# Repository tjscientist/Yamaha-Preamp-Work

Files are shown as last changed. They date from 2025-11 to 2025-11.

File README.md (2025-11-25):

# Yamaha Electric Grand (CP-70 and CP-80) Preamp Work

This all started out as a "simple" CP-80 restoration and (as usual) turned into a year long project... And still continues. Once I started really digging into things, I realized I needed to document my work both in words and video. Initially this documentation was simply so I remembered what I was doing but eventually, I realized there were others out there struggling with the same issues I had been running into. These issues are primarily spare parts, readable schematics, and in depth repair knowledge. To that end, I decided to put my work up here on github so that others could not only benefit from what I have done, but also point out any mistakes I may be making as well as contribute their own knowledge.

What you see up here currently (as of November 2025) are a collection of files, specs, and simulations I have put together and am trying to get organized into something cohesive. Below I will delineate each section and what is in it. As always, please feel free to comment, ask questions, and/or add your own experiences.

This is still an ongoing endeavor and there is much I want to do. I am always open to suggestions.

## Why Even Bother?

I know a lot of people will look at this and just ask, "Why not just do the direct out modification and call it all good?"

The simple answer is I did do that and it sounds pretty good. Then I ran it through my Art Pro Tube preamp... Nice. Then through my restored BOSS CE-1.. Better. Then I wanted the nice stereo tremolo you get from the original preamp and had to work on that. Finally, I just thought why not get back to basics. Do what I do best which is restore everything to as original as possible. So that is what I am doing. I love buying, restoring, and using vintage equipment and I have a lot of it. Several Fender Rhodes pianos, Clavinets, Wurlitzers, B3, A100... And the list goes on. And I know there are many others out there just as crazy as I am when it comes to this, so here we are.

## Altium Files

I use Altium in me every day life as my primary tool for designing electronic schematics and PCBs but I do understand that not everyone has access to this tool. If you do have access to Altium, you will find the entire schematic and part libraries in the **Altium Files** folder. On the other hand, if you do not have access to Altium, do not despair as you will find what is known as a Smart PDF of the schematic in the **Documents** folder named "Schematic - CP80 Preamp - SmartPDF."

## SmartPDF Schematic

The smartPDF schematic, named "Schematic - CP80 Preamp - SmartPDF", is a very useful document. In it you will find the preamp schematic which I have redrawn and find much more readable. But wait, there's more! By clicking on any part in the schematic, you will get a pop-up which includes the original part number, manufacturer, part description, and a comment field where I have listed what I suggest to use if you want or need to replace that particular part. Some parts have a lot of information while others do not require so much. Below is an example showing what appears when FET1 is clicked:

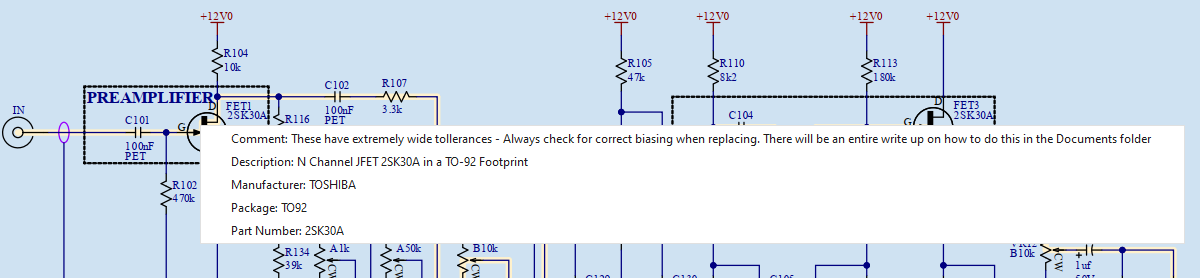
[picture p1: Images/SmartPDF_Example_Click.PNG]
SmartPDF_Example_Click


Additionally on the schematic, you will see my notes and highlights. The following is from the bottom of the PDF and explains a bit of the information it contains:

*The MCD-527 LDRs (Light Dependent Resistors):*
*TRD101 and TRD102, are split into 2 parts each. These parts are the LED light source (Part B - Highlighted Green) and the Photoresistor (Part A - Highlighted Red).* 

*Signal Flow:*
*Audio enters from the piezo pickups at the upper left and is highlighted in yellow all the way to the buffer amplifiers where it is split into unvbalanced  high and balanced low impeadance stereo signals. The left high impeadance signal is highlighted in red while the right high impeadance signal is highlighted in green. The left low impeadance signal is highlighted in purple while the right low impeadance signal is highlighted in pink.*

*The tone brilliance signals are detailed on the far right, external controls are labeled in bold red, and adjustment pots are highlighted in bright green boxes.*

*Clicking on any component in the PDF file will show the original part number, part specifications, and notes on replacement parts.*

*Using the PDF file bookmarks, you can jump to any specific part or net.*

## Part Data Sheets

This is pretty self explanatory. In the Part Data Sheets folder you will find data sheets for some of the parts in the preamp. Most of these are simply data sheets that are hard to find, so I included them here as an easy reference. Additionally, when I am researching acceptable alternatives, I put those data sheets in there as well. I may add more over time.

## TINA-TI Spice Files

For those that are not familiar with TINA-TI, it is a free, SPICE-based circuit simulation software from Texas Instruments (TI) and DesignSoft that is used to design, test, and analyze analog, digital, and mixed electronic circuits. It includes a graphical interface for schematic capture, analysis capabilities like DC, transient, and frequency domain, and virtual instruments. The program is a simplified version of the full TINA Design Suite but remains powerful enough for complex circuits.  For more information check out TINA-TI's website: [https://www.ti.com/tool/TINA-TI](https://www.ti.com/tool/TINA-TI).

The main files TINA uses have a TSC extension and the graphing files have a tdr extension. Below you can see the schematic which I have entered into TINA (CP-80.TSC):

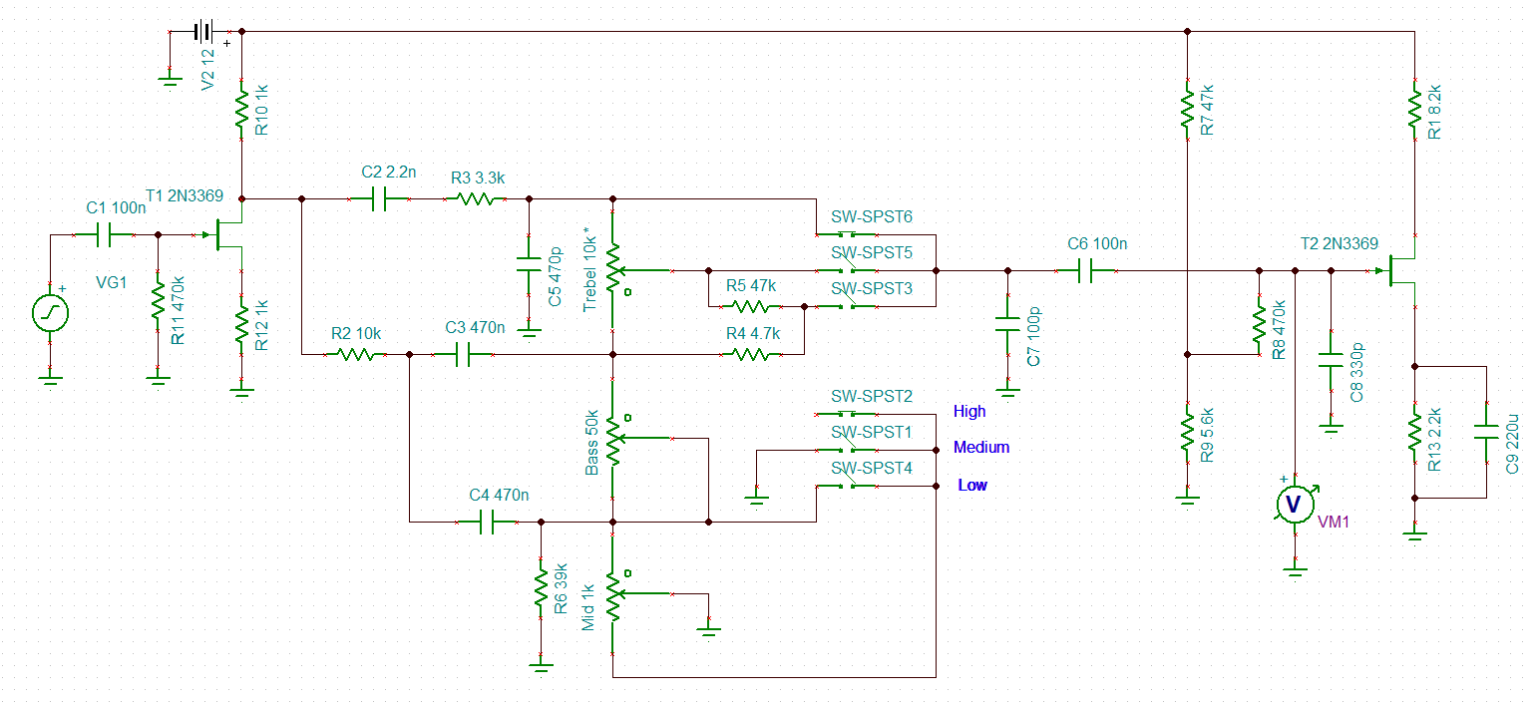
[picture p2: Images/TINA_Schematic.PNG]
TINA_Schematic


There is a document in the Documents folder (and eventually a video link) "CP-80 Preamp TINA-TI Simulations" that explains the circuit and how to generate simulations like the one below (this one shows the frequency response from 1hZ to 20kHz with the Brilliance Switch set to High, Bass and Treble controls at 99%, and the Mid control set to 10 different settings as shown in the legend of the plot):

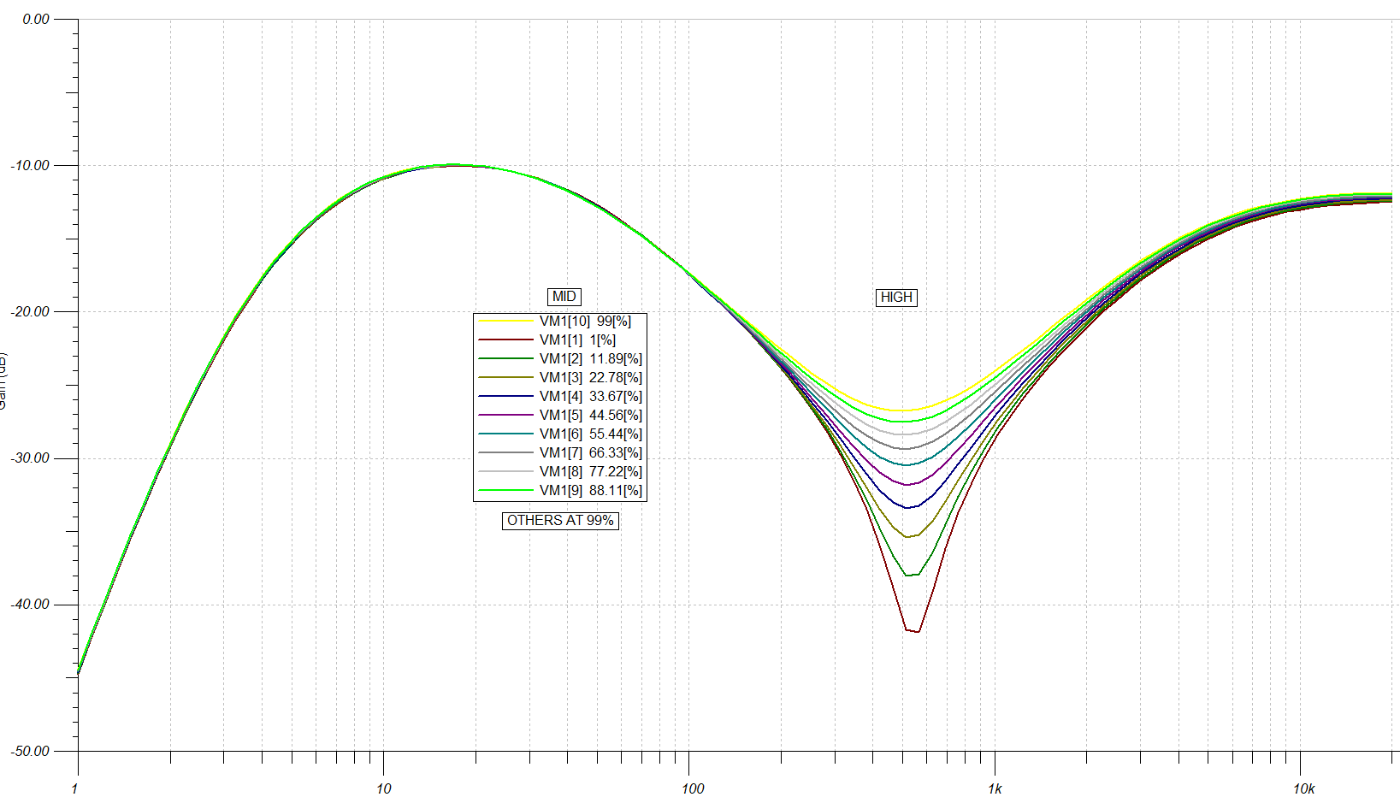
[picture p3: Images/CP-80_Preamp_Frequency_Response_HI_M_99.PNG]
CP-80_Preamp_Frequency_Response_HI_M_99


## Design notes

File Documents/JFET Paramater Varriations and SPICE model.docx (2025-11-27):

JFET SPICE MODEL:

The SPICE model for our N Channel JFET, the 2SK30 is shown below (the note on the last entry refers to a CQ magazine article from July, 1988 as the model source):

*2SK30
*id(R 0.3-0.75 / O 0.6-1.4 / Y 1.2-3.00 / GR 2.6-6.5)
.model J2SK30r NJF(vto=-0.8v beta=0.75m lambda=0 cgd=2.6p cgs=8.2p
+ dev 10% LOT 60%)
.model J2SK30o NJF(vto=-1.1v beta=0.75m lambda=0 cgd=2.6p cgs=8.2p
+ dev 10% LOT 60%)
.model J2SK30y NJF(vto=-1.8v beta=0.75m lambda=0 cgd=2.6p cgs=8.2p
+ dev 10% LOT 60%)
.model J2SK30gr NJF(vto=-2.8v beta=0.75m lambda=0 cgd=2.6p cgs=8.2p
+ dev 10% LOT 60%)

.model J2SK30atm NJF(beta=.768m vto=-2.70 cgd=2.6p cgs=8.2p dev 10% LOT 60%)
* CQ 1988/7

DEV and LOT in the JFET SPICE Model:
DEV 10% LOT 60% is used in SPICE simulations to define statistical variations for device parameters, enabling worst-case and Monte Carlo analyses.

Explanation of the Parameters:
These parameters define how much a specific model parameter (like a transistor's current gain or a resistor's value) can vary from its nominal value during a statistical simulation. This is crucial for checking circuit robustness and manufacturing yield.

- DEV (Deviation): This specifies the intra-die variation, which is the random mismatch between components on the same integrated circuit (die). The value 10% means the parameter can randomly vary by up to ±10% from its nominal value due to local process variations.
- LOT: This specifies the inter-die (or lot-to-lot) variation. This accounts for the systematic shift in parameters that affects all devices on an entire wafer or in a specific manufacturing batch (lot). The value 60% means the parameter's nominal value can vary by up to ±60% from the global average value across different manufacturing lots.

IDSS Classification note in the data sheet:
In a JFET datasheet, the IDSS classification note refers to the practice of the manufacturer sorting JFETs into different performance grades (listed as R, O, Y, and GR in the 2SK30 datasheet) based on their specific, measured Zero-Gate-Voltage Drain Current.

Understanding the Classification:

- IDSS Definition: I_(DSS) is the maximum current that can flow from the drain to the source when the gate-source voltage ( V_(GS) ) is 0V (gate and source shorted together) and the JFET is in the saturation region.
- Manufacturing Variability: The exact value of I_(DSS) and the associated pinch-off voltage ( V_P ) can vary significantly even among JFETs of the same part number due to slight inconsistencies in the manufacturing process. This variability is inherent to JFETs and is comparable to the beta factor ( h_(FE) ) in BJTs.
- Binning/Grading: To provide designers with more predictable components for specific applications, manufacturers test the produced JFETs and group (or "bin") them into different classifications, each with a tighter range of I_(DSS) values than the overall part number might suggest.

Practical Implications for Design:
The classification allows designers to select the appropriate JFET grade for their circuit, particularly when the design depends on a specific current range or requires matched pairs for differential amplifiers.

SPICE Syntax for a JFET:
The SPICE syntax for an N-channel JFET model is .MODEL ModelName NJF(parameters), where ModelName is a user-defined name for the model and parameters are a list of values that define the JFET's characteristics, such as beta, Vto, rd, and rs. An example of a JFET element in the netlist is Jname <drain> <gate> <source> ModelName.

Model definition:

- MODEL: A directive used to define a model.
- ModelName: A unique name you assign to this specific JFET model.
- NJF: Specifies that this is an N-channel Junction Field-Effect Transistor model.
- (parameters): A list of key-value pairs that define the JFET's electrical properties.
  - beta: The transconductance parameter.
  - Vto: The pinch-off voltage.
  - rd: The drain resistance.
  - rs: The source resistance.
  - is: Saturation current.
  - lambda: Channel-length modulation parameter.
  - cgs: Gate-source capacitance.
  - cgd: Gate-drain capacitance.
  - fc: Forward-bias cap voltage dependence coefficient.
  - m: Cap coefficient variation with gate voltage.
  - n: Coefficient for gate voltage dependence of capacitance.
  - xti: Temperature dependence of saturation current.

Element instance:

- Jname: A unique name for the JFET device instance in the circuit.
- <drain>: The node connected to the drain terminal.
- <gate>: The node connected to the gate terminal.
- <source>: The node connected to the source terminal.
- ModelName: The name of the model you are referencing

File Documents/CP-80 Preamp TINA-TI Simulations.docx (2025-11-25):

This document is intended to be used with the TINA-TI program (www.ti.com/tool/TINA-TI) loaded with the CP-80.TSC spice file from the TINA Spice Files Folder and the 2SK30 N-channel JFET data sheet (located in the “Part Data Sheets” folder).

The main reasons I decided to go through the work of entering the entire schematic into TINA are as follows:

- JFETs have extremely wide parameters (e.g. VGS can range from -0.4 to -5V and IDSS can range from 0.3 to 6.5mA) so I wanted to characterize the circuit over this range.
- Certain parts are very difficult to find if they need replacement, such as the 2 audio transformers for the balanced line out. I want to know that my replacements will not alter the original sound.

The schematic drawn in the CP-80 Spice file is a slightly modified version of the actual CP-80 preamp schematic. As you can see, the 3 position Brilliance switch is set up to manually open and close each contact. Additionally, you can see there are 4 options for the 2SK30 JFET. These options cover the 4 IDSS classifications from the data sheet.

Before we continue, we need to talk about JFETs, their extremely wide parameter set (i.e. Very large part to part variations), and a couple of definitions.

IDSS (zero-gate-voltage drain current) is a characteristic that varies between individual devices, even those of the same part number. However, a JFET's characteristics are determined by its IDSS value, and this value, along with the pinch-off voltage ( V_(GS(off)) ), can be used to classify or group devices for specific applications like voltage-controlled resistors or current sources. Devices are primarily classified by their type, either N-channel or P-channel, which dictates the polarity of the gate-source voltage required to control the drain current.

How JFETs are classified and characterized

- Channel Type: The most fundamental classification is the channel type, which can be either N-channel or P-channel. In our case the only JFETs we use are the 2SK30 N-channel JFET.
  - N-channel: Requires a negative gate-source voltage to decrease drain current.
  - P-channel: Requires a positive gate-source voltage to decrease drain current.
- IDSS and V_(GS(off)) : Within a channel type, devices can be grouped based on IDSS and V_(GS(off)) values, which are measured through testing. When manufacturers do this, it is called binning.
  - IDSS (Zero-gate-voltage drain current): The drain-source current when the gate-source voltage ( V_(GS) ) is zero. This is a measure of the maximum current a JFET can conduct at V_(GS) =0 .
  - V_(GS(off)) (Pinch-off voltage): The gate-source voltage required to turn the JFET off (reduce the drain current to near zero).
  - These two parameters are directly related, and a higher IDSS will have a different corresponding V_(GS(off)) value than a lower IDSS.

Applications where IDSS and VGS(off) are used for grouping or binning

- Matching: Devices can be grouped or "matched" by similar IDSS and V_(GS(off)) values for applications where this is critical, such as stereo audio amplifiers or balanced circuits.
- Current Source: A JFET with a specific IDSS can be used to create a current source or sink. By adding a resistor from the source to ground, the current can be set to a specific value, and the IDSS value of the device can be used to calculate the appropriate resistor value.
- Voltage Controlled Resistor: In a voltage-controlled resistor application, the IDSS value is used in conjunction with V_(GS(off)) to select devices that have the same "on-resistance" ( R_(DS(on)) ) range.

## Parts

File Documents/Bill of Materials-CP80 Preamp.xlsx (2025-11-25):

Name | Description | Designator | Quantity | Manufacturer 1 | Manufacturer Part Number 1 | Supplier 1 | Supplier Part Number 1
1N4148 | General purpose Rectifier Diode, 300mA, 35V V(RRM) If replacing and you cannot find the original, a 1N4148 should be fine | D202 | 1 | onsemi | 1N4148 | DigiKey | 1N4148FS-ND
1N5231BTR | Zener Diode 5.1 V 500 mW 5% If replacing, any 5V1 zener capable of 500mW is fine | D101, D102 | 2 | Microchip | 1N5231B/TR | Mouser | 494-1N5231B/TR
1N5246B | Zener Diode 16V2 500 mW 5% If replacing, any 16V2 zener with 500mW capability will work. | D201 | 1 | onsemi | 1N5246BTR | DigiKey | 1N5246BTRFSCT-ND
105BPS100M | 1uf, 50V, 20%, Electrolytic If these need replacement, just use a low ESR 1uF, 50V, 10% or 20% Electrolytic that is the correct physical size | C107, C109, C114, C121, C122 | 5 | Cornell Dubilier | 105BPS100M | DigiKey | 105BPS100M-ND
112AX | Phone Jack, 6.35mm (0.250", 1/4", Mono Connector, 1 Switch Contact If replacing, replace with same high quality | J1, J2, J3, J4 | 4 | Switchcraft | 112AX | DigiKey | SC1316-ND
225BPS050M | 2.2uF ±20% 16V BiPolar Electrolytic If these are replaced, be sure to use BiPolar Electrolytics. I would go with ±10% tollerance and a minimum 25V. Just make sure they physically are the correct size. | C124, C127 | 2 | Cornell Dubilier | 225BPS050M | DigiKey | 225BPS050M-ND
3266W-1-103LF | 10k Linear taper 20% .250W carbon Adjustable Resistor - Trimmer If replacing, use a 1/4W cermet multi turn with 10% tolerance as they are much better. Find a physical size that works... I will do more research on these as I would also (personally) use a multiturn pot if I can find one that fits. | VR12 | 1 | Bourns | 3266W-1-103LF | DigiKey | 3266W-103LF-ND
3266W-1-104LF | 100k Linear taper 20% .250W carbon Adjustable Resistor - Trimmer If replacing, use a 1/4W cermet multi turn with 10% tolerance as they are much better. Find a physical size that works... I will do more research on these as I would also (personally) use a multiturn pot if I can find one that fits. | VR8, VR9, VR10, VR11 | 4 | Bourns | 3266W-1-104LF | DigiKey | 3266W-104LF-ND
3266W-1-253LF | Original was 22k Linear 20% .250W carbon Adjustable Resistor - Trimmer If replacing, use a 1/4W cermet multi turn with 10% tolerance as they are much better. I am using a 25k as they are much easier to source and it will work just fine. Find a physical size that works... I will do more research on these as I would also (personally) use a multiturn pot if I can find one that fits. | VR7 | 1 | Bourns | 3266W-1-253LF | DigiKey | 3266W-253LF-ND
B32671L1222J000 | 2200pF ±20% 20V (or higher) PET Capacitor These were originally Mylar Film (PET) but I suggest replacing with metallized polypropylene (MKP / PP). Just ensure a propper lead spacing and fit. | BH-C102, BL-C102, BM-C102, C102, C106 | 5 | EPCOS | B32671L1222J000 | DigiKey | 495-3206-ND
BC549BTA | Small Signal Bipolar Transistor, 0.6A I(C), 40V V(BR)CEO, 1-Element, NPN, Silicon, TO-236 If replacing, a BC549BTA or equivelant will work fine. These are just for turnming on the LEDs in the LDRs. | TR101, TR102, TR201 | 3 | onsemi | BC549BTA | DigiKey | BC549BTACT-ND
ECW-FE2W104JA | 100nF (0.1uf) ±20% 20V (or higher) PET Capacitor These were originally Mylar Film (PET) but I suggest replacing with metallized polypropylene (MKP / PP). Just ensure a propper lead spacing and fit. | BH-C103, BL-C103, BM-C103, C101, C103, C112, C113, C115, C117, C119, C120, C126 | 12 | Panasonic | ECWFE2W104JA | DigiKey | 10-ECW-FE2W104JA-ND
GD90025 | The original was a GD90025 - I think these can be replaced with Hammond audio signal transformers... I need to put these on the analyzer to see. | LT1, LT2 | 2
L7812ABV | Originally a FS7812L Linear Voltage Regulator IC Positive Fixed 1 Output 1.5A TO-220 If replacing, there are many pin for pin compatible devices | IC201 | 1 | STMicroelectronics | L7812ABV | DigiKey | 497-1449-5-ND
Lever Switch | Lever Switch, 2P3T - Unknown replacement as of yet. | S1 | 1
MFR-25FTE52-1K | 1k 10% 1/4 Watt Resistor All resistors are 10% 1/4 Watt. I suggest any replacement use 1% 1/4 Watt metal film. | R103, R122 | 2 | Yageo Group | MFR-25FTE52-1K | DigiKey | 13-MFR-25FTE52-1KCT-ND
MFR-25FTE52-1K2 | 1k2 10% 1/4 Watt Resistor All resistors are 10% 1/4 Watt. I suggest any replacement use 1% 1/4 Watt metal film. | R202 | 1 | Yageo Group | MFR-25FTE52-1K2 | DigiKey | 13-MFR-25FTE52-1K2CT-ND
MFR-25FTE52-2K2 | 2k2 10% 1/4 Watt Resistor All resistors are 10% 1/4 Watt. I suggest any replacement use 1% 1/4 Watt metal film. | R109, R120, R151, R153, R204, R205 | 6 | Yageo Group | MFR-25FTE52-2K2 | DigiKey | 13-MFR-25FTE52-2K2CT-ND
MFR-25FTE52-3K3 | 3k3 10% 1/4 Watt Resistor All resistors are 10% 1/4 Watt. I suggest any replacement use 1% 1/4 Watt metal film. | BH-R107, BL-R107, BM-R107, R107 | 4 | Yageo Group | MFR-25FTE52-3K3 | DigiKey | 13-MFR-25FTE52-3K3CT-ND
MFR-25FTE52-4K7 | 4k7 10% 1/4 Watt Resistor All resistors are 10% 1/4 Watt. I suggest any replacement use 1% 1/4 Watt metal film. | BH-RS2, BL-RS2, BM-RS2, RS2 | 4 | Yageo Group | MFR-25FTE52-4K7 | DigiKey | 13-MFR-25FTE52-4K7CT-ND
MFR-25FTE52-5K6 | 5k6 10% 1/4 Watt Resistor All resistors are 10% 1/4 Watt. I suggest any replacement use 1% 1/4 Watt metal film. | R108, R126, R158, R161, R206 | 5 | Yageo Group | MFR-25FTE52-5K6 | DigiKey | 13-MFR-25FTE52-5K6CT-ND
MFR-25FTE52-8K2 | 8k2 10% 1/4 Watt Resistor All resistors are 10% 1/4 Watt. I suggest any replacement use 1% 1/4 Watt metal film. | R110 | 1 | Yageo Group | MFR-25FTE52-8K2 | DigiKey | 13-MFR-25FTE52-8K2CT-ND
MFR-25FTE52-10K | 10k 10% 1/4 Watt Resistor All resistors are 10% 1/4 Watt. I suggest any replacement use 1% 1/4 Watt metal film. | BH-R116, BL-R116, BM-R116, R104, R116, R152, R162 | 7 | Yageo Group | MFR-25FTE52-10K | DigiKey | 13-MFR-25FTE52-10KCT-ND
MFR-25FTE52-22K | 22k 10% 1/4 Watt Resistor All resistors are 10% 1/4 Watt. I suggest any replacement use 1% 1/4 Watt metal film. | R135, R136 | 2 | Yageo Group | MFR-25FTE52-22K | DigiKey | 13-MFR-25FTE52-22KCT-ND
MFR-25FTE52-27K | 27k 10% 1/4 Watt Resistor All resistors are 10% 1/4 Watt. I suggest any replacement use 1% 1/4 Watt metal film. | R115, R129, R132, R139, R143, R147 | 6 | Yageo Group | MFR-25FTE52-27K | DigiKey | 13-MFR-25FTE52-27KCT-ND
MFR-25FTE52-39K | 39k 10% 1/4 Watt Resistor All resistors are 10% 1/4 Watt. I suggest any replacement use 1% 1/4 Watt metal film. | BH-R134, BL-R143, BM-R143, R111, R112, R134, R156, R157, R159, R160 | 10 | Yageo Group | MFR-25FTE52-39K | DigiKey | 13-MFR-25FTE52-39KCT-ND
MFR-25FTE52-47K | 47k 10% 1/4 Watt ResistorAll resistors are 10% 1/4 Watt. I suggest any replacement use 1% 1/4 Watt metal film. | BH-RS1, BL-RS1, BM-RS1, R105, R125, RS1 | 6 | Yageo Group | MFR-25FTE52-47K | DigiKey | 13-MFR-25FTE52-47KCT-ND
MFR-25FTE52-100K | 100k 10% 1/4 Watt Resistor All resistors are 10% 1/4 Watt. I suggest any replacement use 1% 1/4 Watt metal film. | R117, R119, R130, R133, R140, R144, R148, R154, R155 | 9 | Yageo Group | MFR-25FTE52-100K | DigiKey | 13-MFR-25FTE52-100KCT-ND
MFR-25FTE52-100R | 100 10% 1/4 Watt Resistor All resistors are 10% 1/4 Watt. I suggest any replacement use 1% 1/4 Watt metal film. | R201, R203 | 2 | Yageo Group | MFR-25FTE52-100R | DigiKey | 13-MFR-25FTE52-100RCT-ND
MFR-25FTE52-180K | 180k 10% 1/4 Watt Resistor All resistors are 10% 1/4 Watt. I suggest any replacement use 1% 1/4 Watt metal film. | R113, R127, R128, R137, R141, R145 | 6 | Yageo Group | MFR-25FTE52-180K | DigiKey | 13-MFR-25FTE52-180KCT-ND
MFR-25FTE52-220K | 220k 10% 1/4 Watt Resistor All resistors are 10% 1/4 Watt. I suggest any replacement use 1% 1/4 Watt metal film. | R114, R123, R131, R138, R142, R146 | 6 | Yageo Group | MFR-25FTE52-220K | DigiKey | 13-MFR-25FTE52-220KCT-ND
MFR-25FTE52-330R | 330 10% 1/4 Watt Resistor All resistors are 10% 1/4 Watt. I suggest any replacement use 1% 1/4 Watt metal film. | R118, R124, R149, R150 | 4 | Yageo Group | MFR-25FTE52-330R | DigiKey | 13-MFR-25FTE52-330RCT-ND
MFR-25FTE52-470K | 470k 10% 1/4 Watt Resistor All resistors are 10% 1/4 Watt. I suggest any replacement use 1% 1/4 Watt metal film. | R102, R106, R121 | 3 | Yageo Group | MFR-25FTE52-470K | DigiKey | 13-MFR-25FTE52-470KCT-ND
NSL-32SR2S | This original part was a MCD-527 LDR (Light Dependent Resistor). If replacing, the Advanced Photonix NSL-32SR2S OPTOISO PHOTOCELL OPTOCOUPLER is a very close alternative and is available on DigiKey. I will do more research on this (put one in a PreAmp) to see if any other tweaks are necessary. | TRD101, TRD102 | 2 | Advanced Photonix | NSL-32SR2S | DigiKey | NSL-32SR2S-ND
P092N-QC20BR20K | 20k Ohm 2 Gang Linear Through Hole Potentiometer 1.0 Turns Carbon 0.125W, 1/8W PC Pins Replace with Conductive Plastric or Cermet. Ensure proper mechanical fit. | VR1, VR5 | 2 | BI Technologies | P092N-QC20BR20K | Master Electronics | P092N-QC20BR20K
P160KN-0QD15B10K | 10k Ohm 1 Gang Linear Through Hole Potentiometer 1.0 Turns Carbon 0.125W, 1/8W PC Pins Replace with conductive plastic | VR4 | 1 | BI Technologies | P160KN-0QD15B10K | DigiKey | 987-1308-ND
P160KNP-0FC25A50K | 50k Ohm 1 Gang Logarithmic Through Hole Potentiometer 1.0 Turns Carbon 0.125W, 1/8W PC Pins Replace with conductive plastic. | BH-VR2, BL-VR2, BM-VR2, VR2 | 4 | BI Technologies | P160KNP-0FC25A50K | Mouser | 858-P160KNP0FC25A50K
P160KNP-0QC15A1K | 1k Ohm 1 Gang Logarithmic Through Hole Potentiometer 1.0 Turns Carbon 0.125W, 1/8W PC Pins Replace with conductive plastic. | BH-VR3, BH-VR4, BL-VR3, BL-VR4, BM-VR3, BM-VR4, VR3 | 7 | BI Technologies | P160KNP-0QC15A1K | Mouser | 858-P160KNP0QC15A1K
PDB182-K220K-104B | 100k Ohm 2 Gang Linear Through Hole Potentiometer 1.0 Turns Carbon 0.125W, 1/8W PC Pins Replace with conductive plastic or cermet if possible. This one is carbon. | VR6 | 1 | Bourns | PDB182-K220K-104B | DigiKey | PDB182-K220K-104B-ND
PFR5331J630J11L4BULK | 330pF ±20% 20V (or higher) PET Capacitor These were originally Mylar Film (PET) but I suggest replacing with metallized polypropylene (MKP / PP). Just ensure a propper lead spacing and fit. | C130, C131 | 2 | KEMET | PFR5331J630J11L4BULK | DigiKey | 399-7718-ND
POWER SW | Slide switch. Need to find replacement part number | PS1 | 1
R76MF24705050J | 47nF (0.047uf) ±20% 20V (or higher) PET Capacitor These were originally Mylar Film (PET) but I suggest replacing with metallized polypropylene (MKP / PP). Just ensure a propper lead spacing and fit. | C104 | 1 | KEMET | R76MF24705050J | DigiKey | 399-R76MF24705050J-ND
R76QF0470DQ00J | 470pF ±20% 20V (or higher) PET Capacitor These were originally Mylar Film (PET) but I suggest replacing with metallized polypropylene (MKP / PP). Just ensure a propper lead spacing and fit. | BH-C128, BL-C128, BM-C128, C108, C128, C202 | 6 | KEMET | R76QF0470DQ00J | DigiKey | 399-R76QF0470DQ00JCT-ND
R76UI0100SE40J | 100pF ±20% 20V (or higher) PET Capacitor These were originally Mylar Film (PET) but I suggest replacing with metallized polypropylene (MKP / PP). Just ensure a propper lead spacing and fit. | BH-C129, BL-C109, BM-C129, C129 | 4 | KEMET | R76UI0100SE40J | DigiKey | 399-R76UI0100SE40J-ND
RC4558IP | Dual General-Purpose Operational Amplifier, 10 to 30 V, 0 to 70 degC, 8-pin SOP (PW8), Green (RoHS & no Sb/Br) If replacing, replace with the same as removed. These are still available. | U102 | 1 | Texas Instruments | RC4558IP | DigiKey | 296-17460-5-ND
Switch, Toggle, DPST | This is a specialized switch with no known replacement. Will research more. | S2 | 1
T356A474K035AT | .47µF TANT 20% 16V The originals were most likely 20% @ 16V with an ESR of 50 Ohms @ 100Khz. If replaced I would use 10%, 20V with 5 Ohm ESR @ 100Khz | BH-C110, BH-C111, BL-C110, BL-C111, BM-C110, BM-C111, C110, C111 | 8 | KEMET | T356A474K035AT | DigiKey | 399-3617-ND
Transistor, JFET, N Ch, TO-92 | Original was an N Channel JFET 2SK30A in a TO-92 Footprint These have extremely wide tollerances - Always check for correct biasing when replacing. There will be an entire write up on how to do this in the Documents folder | FET1, FET2, FET3, FET4, FET5, FET6, FET7, FET8, FET9 | 9 | Toshiba | 2SK30A-Y | Win Source | 18270-2SK30A-Y
UES1H100MPM | 10µF 20% 25V electrolytic Capacitor If replacing, use a 10uF 10% 50V electrolytic woth a low ESR. Going to 50V will allow for 10% and a lower ESR as long as it still physically fits well. | C116, C118, C123, C125 | 4 | Nichicon | UES1H100MPM | DigiKey | 493-15033-ND
UKT1V221MPD | 220µF 20% 25V Electrolytic Capacitor If replacing, use a good quality 220uF 20% (or better) 25V Electrolytic Capacitor that physically fits correctly | C105, C201, C203, C204 | 4 | Nichicon | UKT1V221MPD | DigiKey | 493-15452-ND
WP7113ID | Single Color (Red) LED If replacing, any standard LED with a forward voltage of 1V7 to 2V2 will work fine | D1 | 1 | Kingbright | WP7113ID | DigiKey | 754-1264-ND
XLR-2A-32 | 2 Position Circular Connector Plug, Female Sockets Solder XLR-2A-32 is the male version on the piano while XLR2A11C Is the female connector on the cable | J201 | 1 | ITT / Cannon | XLR2A32 | Master Electronics | XLR2A32
XLR-3-32 | 3 Position Circular Connector Receptacle, Male Pins Solder Cup Replace with same if replacing | J5, J6 | 2 | ITT / Cannon | XLR332 | DigiKey | 1003-1238-ND

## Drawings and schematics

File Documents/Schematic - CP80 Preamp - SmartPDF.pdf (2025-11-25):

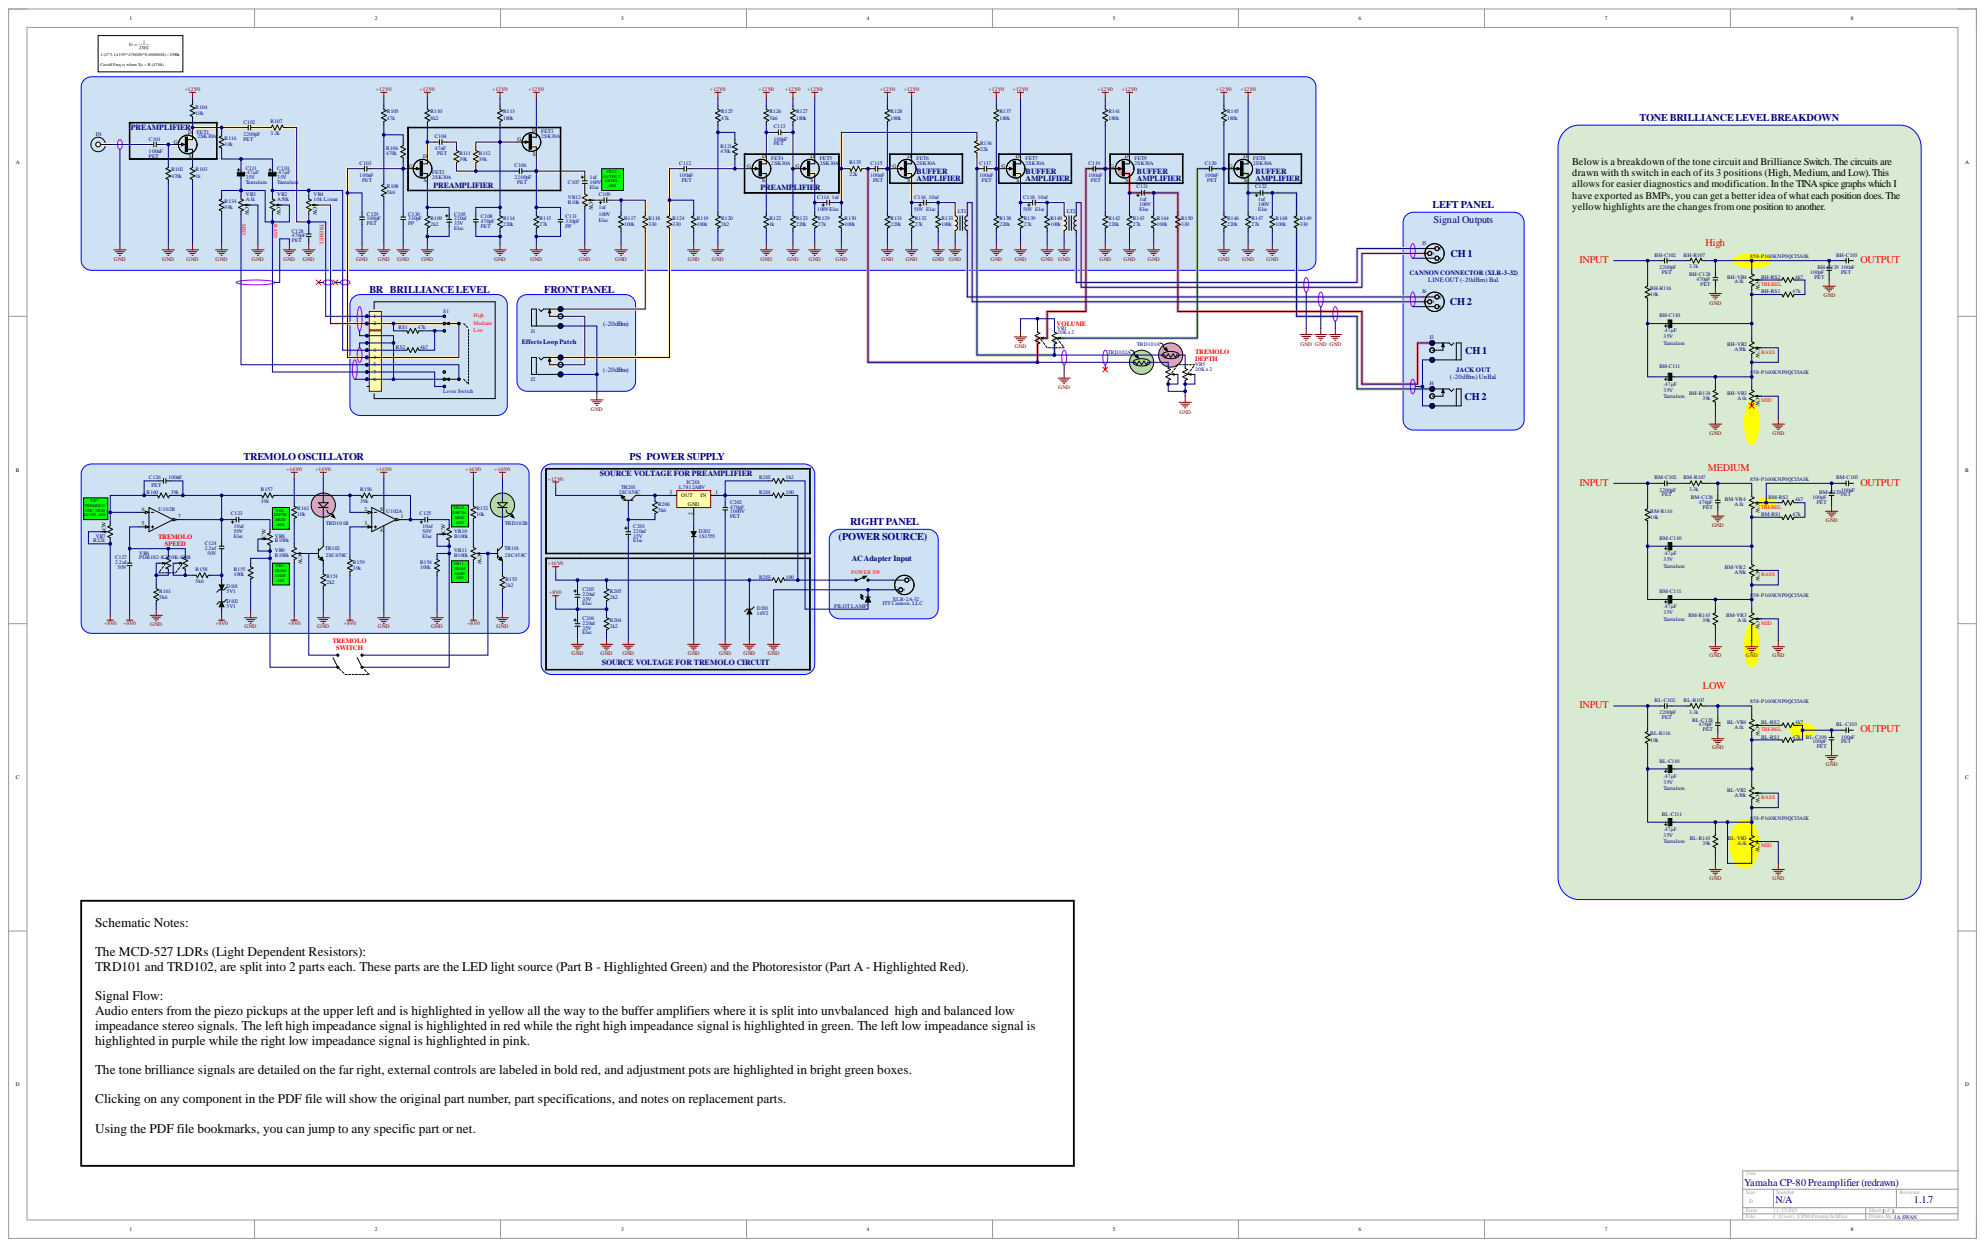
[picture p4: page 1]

Cutoff Freq is where Xc = R (470k)

Below is a breakdown of the tone circuit and Brilliance Switch. The circuits are
drawn with th switch in each of its 3 positions (High, Medium, and Low). This

allows for easier diagnostics and modification.In the TINAspice graphs which I
have exported as BMPs, you can get a better idea of what each position does. The
yellow highlights are the changes from one position to another.

C203 R205 220uf 35V Elec 2k2

PILOT LAMP

XLR-2A-32 ITT Cannon, LLC

SOURCE VOLTAGE FOR TREMOLO CIRCUIT

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

Using the PDF file bookmarks, you can jump to any specific part or net.

Title
Yamaha CP-80 Preamplifier (redrawn)

Size D | N/A Number | JA SWAN Revision 1.1.7 1

Date: 11/25/2025 File: C:\Users\..\CP80 Preamp.SchDoc | Sheet of 1 Drawn By:

Line# | Name | Description | Designator | Quantity | Manufacturer 1 | Manufacturer Part Number 1 | Supplier 1 | Supplier Part Number 1
| 1N4148 | General purposeRectifier Diode, 300mA, 35VV(RRM)
| | If replacingand you cannot find theoriginal, a 1N4148should befine | D202 | | 1 onsemi | 1N4148 | DigiKey | 1N4148FS-ND
1N5231BTR | Zener Diode5.1V500mW5% If replacing, any5V1zener capableof 500mWis fine | D101, D102 | | 2 Microchip | 1N5231B/TR | Mouser | 494-1N5231B/TR
1N5246B | Zener Diode16V2500mW5% If replacing, any16V2zener with 500mWcapabilitywill work. | D201 | | 1 onsemi | 1N5246BTR | DigiKey | 1N5246BTRFSCT-ND
105BPS100M | 1uf, 50V, 20%, Electrolytic If theseneed replacement, just usea low ESR1uF, 50V, 10%or 20%Electrolytic that is thecorrect physical size | C107, C109, C114, C121, C122 | | 5 Cornell Dubilier | 105BPS100M | DigiKey | 105BPS100M-ND
112AX | PhoneJack, 6.35mm (0.250", 1/4", Mono Connector, 1Switch Contact If replacing, replacewith samehigh quality | J1, J2, J3, J4 | | 4 Switchcraft | 112AX | DigiKey | SC1316-ND
225BPS050M | 2.2uF±20%16VBiPolar Electrolytic If theseare replaced, besure to useBiPolar Electrolytics. I would go with ±10%tolleranceand a minimum 25V. Just makesure theyphysicallyare thecorrect size. | C124, C127 | | 2 Cornell Dubilier | 225BPS050M | DigiKey | 225BPS050M-ND
3266W-1-103LF | 10k Linear taper 20%.250Wcarbon AdjustableResistor - Trimmer If replacing, usea 1/4Wcermet multi turn with 10%toleranceas theyare much better. Find a physical sizethat works... I will do more research on theseas I would also (personally) usea multiturn pot if I can find onethat fits. | VR12 | | 1 Bourns | 3266W-1-103LF | DigiKey | 3266W-103LF-ND
3266W-1-104LF | 100k Linear taper 20%.250Wcarbon AdjustableResistor - Trimmer If replacing, usea 1/4Wcermet multi turn with 10%toleranceas theyare much better. Find a physical sizethat works... I will do more research on theseas I would also (personally) usea multiturn pot if I can find onethat fits. | VR8, VR9, VR10, VR11 | | 4 Bourns | 3266W-1-104LF | DigiKey | 3266W-104LF-ND
3266W-1-253LF | Original was 22k Linear 20%.250Wcarbon AdjustableResistor - Trimmer If replacing, usea 1/4Wcermet multi turn with 10%toleranceas theyare much better. I am usinga 25k as theyare much easier to sourceand it will work just fine. Find a physical sizethat works... I will do more research on theseas I would also (personally) usea multiturn pot if I can find one that fits. | VR7 | | 1 Bourns | 3266W-1-253LF | DigiKey | 3266W-253LF-ND
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

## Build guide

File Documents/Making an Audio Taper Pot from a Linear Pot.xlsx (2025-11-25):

 | Lin Pot | Padding (L to C) |  |  | Voltage
 | 1000 | 200 |  |  | 12
% | Outside (L to R) | Center to left | Center to right | % | Vout1 | Vout2
1 | 999.52 | 9.52 | 10.00 | 1 | 11.89 | 0.11
5 | 990.00 | 40.00 | 50.00 | 5 | 11.52 | 0.48
10 | 966.67 | 66.67 | 100.00 | 10 | 11.17 | 0.83
15 | 935.71 | 85.71 | 150.00 | 15 | 10.90 | 1.10
20 | 900.00 | 100.00 | 200.00 | 20 | 10.67 | 1.33
25 | 861.11 | 111.11 | 250.00 | 25 | 10.45 | 1.55
30 | 820.00 | 120.00 | 300.00 | 30 | 10.24 | 1.76
35 | 777.27 | 127.27 | 350.00 | 35 | 10.04 | 1.96
40 | 733.33 | 133.33 | 400.00 | 40 | 9.82 | 2.18
45 | 688.46 | 138.46 | 450.00 | 45 | 9.59 | 2.41
50 | 642.86 | 142.86 | 500.00 | 50 | 9.33 | 2.67
55 | 596.67 | 146.67 | 550.00 | 55 | 9.05 | 2.95
60 | 550.00 | 150.00 | 600.00 | 60 | 8.73 | 3.27
65 | 502.94 | 152.94 | 650.00 | 65 | 8.35 | 3.65
70 | 455.56 | 155.56 | 700.00 | 70 | 7.90 | 4.10
75 | 407.89 | 157.89 | 750.00 | 75 | 7.35 | 4.65
80 | 360.00 | 160.00 | 800.00 | 80 | 6.67 | 5.33
85 | 311.90 | 161.90 | 850.00 | 85 | 5.77 | 6.23
90 | 263.64 | 163.64 | 900.00 | 90 | 4.55 | 7.45
95 | 215.22 | 165.22 | 950.00 | 95 | 2.79 | 9.21
100 | 166.67 | 166.67 | 1000.00 | 100 | 0.00 | 12.00
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

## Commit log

2025-11-19 Updated Altium Schematic Library and Outjobs
    [CP80 Preamp.PrjPcb, CP80 Preamp.SCHLIB, CP80 Preamp.SchDoc]
2025-11-19 Updated Symbols and readme file
    [CP80 Preamp.PrjPcb, CP80 Preamp.SchDoc]
2025-11-23 Updated Schematic and Part Numbers
    [CP80 Preamp.SchDoc]
2025-11-24 Updated schematics
2025-11-24 Adding parts
    [CP80 Preamp.PrjPcb, CP80 Preamp.SCHLIB, CP80 Preamp.SchDoc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]
2025-11-24 Updated parts and BOM
    [CP80 Preamp.SCHLIB, CP80 Preamp.SchDoc, CP80 Preamp_OLD.SCHLIB]
2025-11-25 Updated data sheets, Clacs, and BOM in Altium
    [CP80 Preamp.PrjPcb, CP80 Preamp.SCHLIB, CP80 Preamp.SchDoc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]
2025-11-25 Updated Altium outjobs. Auto generated BOM and new Schematic (SmartPDF)
    [Bill of Materials-CP80 Preamp.xlsx, CP80 Preamp BOM.xlsx, CP80 Preamp.PrjPcb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]
2025-11-27 Fixed a schematic error and added more documentation
    [CP80 Preamp.PrjPcb, CP80 Preamp.SchDoc]
